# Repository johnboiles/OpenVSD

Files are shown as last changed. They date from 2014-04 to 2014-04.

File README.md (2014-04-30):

OpenVSD
=======
http://github.com/johnboiles/OpenVSD

A small board and accompanying Arduino firmware that allows you to turn a normal diaphragm pump into a variable speed diaphragm pump.

Bill of Materials
-----------------
1x 5V Pressure Sensor

1x IRFZ40 High-power MOSFET

1x MCP1416 MOSFET Driver

2x 0.1uF Capacitor

1x 1uF Capacitor

1x 5V Sparkfun Arduino Pro Micro 

TODO
____
Add flyback diode

Better footprint for screw terminals

Proper footprint for film capacitor

Silkscreen to indicate orientation of Arduino

Switch to default back to pressure switch

Debug LEDs

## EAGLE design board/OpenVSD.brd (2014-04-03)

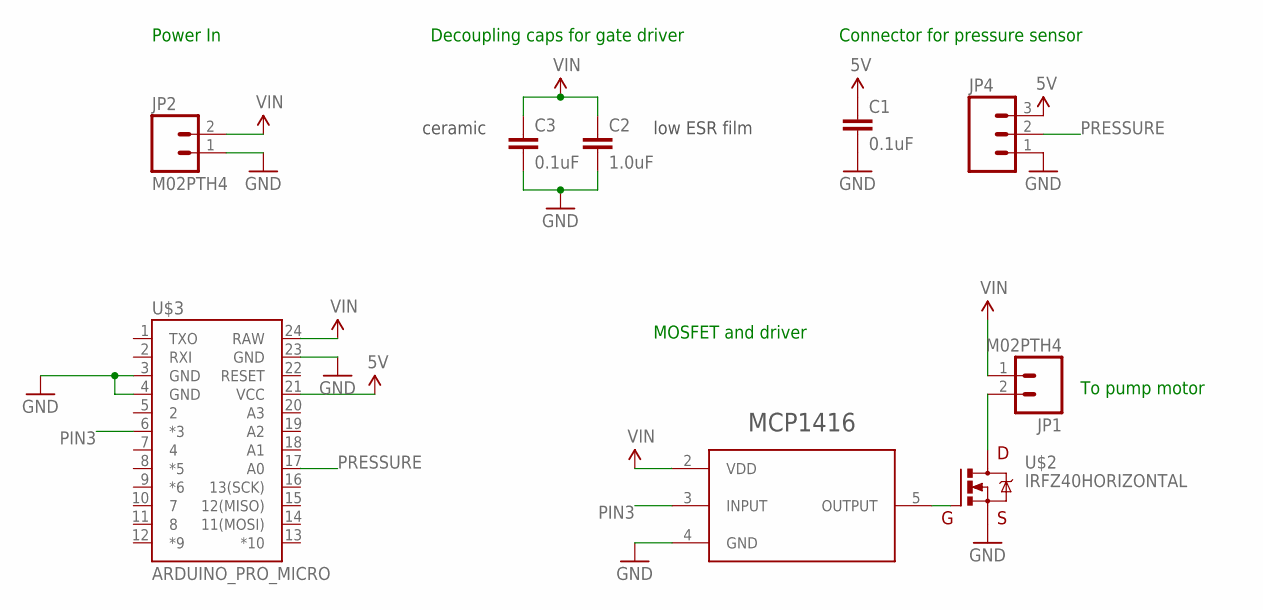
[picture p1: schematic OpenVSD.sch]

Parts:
C1, C3: 0.1uF; 0603-CAP
C2: 1.0uF; 0603-CAP
JP1, JP2: M02PTH4; 1X02_XTRA_BIG
JP4: M03PTH; 1X03
U$1: MCP1416; SOT23-5
U$2: IRFZ40HORIZONTAL; TO220
U$3: ARDUINO_PRO_MICRO

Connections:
5V: C1.1, JP4.3, U$3.21 (VCC)
GND: C1.2, C2.2, C3.2, JP2.1, JP4.1, U$1.4 (GND), U$2.3 (S), U$3.3 (GND), U$3.4 (GND), U$3.23 (GND)
unnamed: U$1.5 (OUTPUT), U$2.1 (G)
PIN3: U$1.3 (INPUT), U$3.6 (*3)
PRESSURE: JP4.2, U$3.17 (A0)
PUMP-: JP1.2, U$2.2 (D)
VIN: C2.1, C3.1, JP1.1, JP2.2, U$1.2 (VDD), U$3.24 (RAW)

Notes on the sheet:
low ESR film
ceramic
Power In
Decoupling caps for gate driver
Connector for pressure sensor
MOSFET and driver
To pump motor

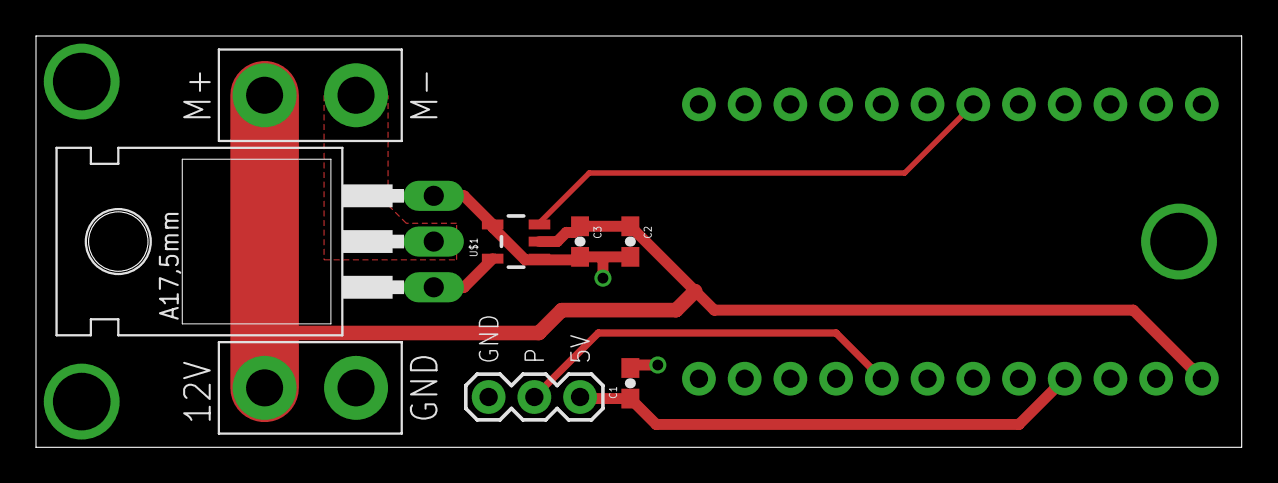
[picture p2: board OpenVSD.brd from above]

Board: 2 copper layers, 67.0 x 22.9 mm, 9 parts (0 on the bottom side), 7 nets.

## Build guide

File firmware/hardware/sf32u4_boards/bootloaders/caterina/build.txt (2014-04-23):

make clean
make PID=0x9209 F_CPU=16000000
copy Caterina.hex Caterina-wiflyin.hex
make clean
make PID=0x9207 F_CPU=8000000
copy Caterina.hex Caterina-lilypadusb.hex
make clean
make PID=0x9205 F_CPU=16000000
copy Caterina.hex Caterina-promicro16.hex
make clean
make PID=0x9203 F_CPU=8000000
copy Caterina.hex Caterina-promicro8.hex 
make clean
make PID=0x2B74 F_CPU=16000000
copy Caterina.hex Caterina-makey.hex
make clean
make PID=0xF100 F_CPU=8000000
copy Caterina.hex Caterina-fio.hex
make clean
make PID=0x920B F_CPU=16000000
copy Caterina.hex Caterina-minibench.hex

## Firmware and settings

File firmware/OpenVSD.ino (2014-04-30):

#include <PID_v1.h>

#define PRESSURE_SENSOR_PIN A0
#define DEBUG_LED_PIN 17
#define MOTOR_CONTROL_PIN 3
#define INITIAL_SETPOINT_PSI 40

#define VCC 5.0f
#define MOTOR_MINIMUM_PWM 100

// TODO: Call the PID method in an OCR interrupt
// TODO: Tune the pid
// https://controls.engin.umich.edu/wiki/index.php/PIDTuningClassical#Trial_and_Error
// http://www.ni.com/white-paper/3782/en/

void SerialReceive();
void SerialSend();
unsigned long serialTime; // This will help us know when to talk with processing

// Define Variables we'll be connecting to
double Setpoint, Input, Output;

// Specify the links and initial tuning parameters
PID myPID(&Input, &Output, &Setpoint, 8, 6, 0, DIRECT);

float readPressureSensor() {
    int analogValue = analogRead(PRESSURE_SENSOR_PIN);
    float voltage = (analogValue / 1024.0f) * VCC;
    // Pressure sensor returns between 0.5V – 4.5V, corresponding to 0-100psi
    float pressure = ((voltage - 0.5) / 4) * 100.0;
    return pressure;
}

ISR(TIMER1_COMPA_vect) {
    // (1 / 100s) * (16000000Hz / 256) = 625
    OCR1A = TCNT1 + 625;
    float pressure = readPressureSensor();
    Input = pressure;
    myPID.Compute();
    uint8_t motorOutput = Output;
    if (motorOutput <= MOTOR_MINIMUM_PWM || Input > 50.0) {
        motorOutput = 0;
    }
    analogWrite(MOTOR_CONTROL_PIN, motorOutput);
}

void setup() {
    // Disable interrupts
    cli();

    TCCR1A = 0;
    TCCR1B = 1 << CS12; // Clock / 256 (31250Hz or .000032)
    TCCR1C = 0; // not forcing output compare
    TCNT1 = 0; // set timer counter initial value (16 bit value)
    TIMSK1 = 1 << OCIE1A; // enable timer compare match 1A interrupt    

    Serial.begin(115200);
    pinMode(DEBUG_LED_PIN, OUTPUT);
    pinMode(PRESSURE_SENSOR_PIN, INPUT);
    pinMode(MOTOR_CONTROL_PIN, OUTPUT);
    digitalWrite(MOTOR_CONTROL_PIN, LOW);

    // Initialize the variables we're linked to
    Input = readPressureSensor();
    Setpoint = INITIAL_SETPOINT_PSI;

    // Turn the PID on
    myPID.SetOutputLimits(MOTOR_MINIMUM_PWM, 255);
    // For now, require manual initiation
    myPID.SetMode(AUTOMATIC);
    Output = 0;
    myPID.SetSampleTime(10);

    // Enable interrupts
    sei();
}

void loop() {
    // Send-receive with processing if it's time
    if (millis() > serialTime) {
        SerialReceive();
        SerialSend();
        serialTime += 350;
    }
}

/********************************************
 * Serial Communication functions / helpers
 ********************************************/


union {                // This Data structure lets
  byte asBytes[24];    // us take the byte array
  float asFloat[6];    // sent from processing and
}                      // easily convert it to a
foo;                   // float array



// getting float values from processing into the arduino
// was no small task.  the way this program does it is
// as follows:
//  * a float takes up 4 bytes.  in processing, convert
//    the array of floats we want to send, into an array
//    of bytes.
//  * send the bytes to the arduino
//  * use a data structure known as a union to convert
//    the array of bytes back into an array of floats

//  the bytes coming from the arduino follow the following
//  format:
//  0: 0=Manual, 1=Auto, else = ? error ?
//  1: 0=Direct, 1=Reverse, else = ? error ?
//  2-5: float setpoint
//  6-9: float input
//  10-13: float output
//  14-17: float P_Param
//  18-21: float I_Param
//  22-245: float D_Param
void SerialReceive()
{
  // read the bytes sent from Processing
  int index=0;
  byte Auto_Man = -1;
  byte Direct_Reverse = -1;
  while(Serial.available()&&index<26)
  {
    if(index==0) Auto_Man = Serial.read();
    else if(index==1) Direct_Reverse = Serial.read();
    else foo.asBytes[index-2] = Serial.read();
    index++;
  }

  // if the information we got was in the correct format,
  // read it into the system
  if(index==26  && (Auto_Man==0 || Auto_Man==1)&& (Direct_Reverse==0 || Direct_Reverse==1))
  {
    Setpoint=double(foo.asFloat[0]);
    //Input=double(foo.asFloat[1]);       // * the user has the ability to send the
                                          //   value of "Input"  in most cases (as
                                          //   in this one) this is not needed.
    if(Auto_Man==0)                       // * only change the output if we are in
    {                                     //   manual mode.  otherwise we'll get an
      Output=double(foo.asFloat[2]);      //   output blip, then the controller will
    }                                     //   overwrite.

    double p, i, d;                       // * read in and set the controller tunings
    p = double(foo.asFloat[3]);           //
    i = double(foo.asFloat[4]);           //
    d = double(foo.asFloat[5]);           //
    myPID.SetTunings(p, i, d);            //

    if(Auto_Man==0) myPID.SetMode(MANUAL);// * set the controller mode
    else myPID.SetMode(AUTOMATIC);             //

    if(Direct_Reverse==0) myPID.SetControllerDirection(DIRECT);// * set the controller Direction
    else myPID.SetControllerDirection(REVERSE);          //
  }
  Serial.flush();                         // * clear any random data from the serial buffer
}

// unlike our tiny microprocessor, the processing ap
// has no problem converting strings into floats, so
// we can just send strings.  much easier than getting
// floats from processing to here no?
void SerialSend() {
    Serial.print("PID ");
    Serial.print(Setpoint);
    Serial.print(" ");
    Serial.print(Input);
    Serial.print(" ");
    Serial.print(Output);
    Serial.print(" ");
    Serial.print(myPID.GetKp());
    Serial.print(" ");
    Serial.print(myPID.GetKi());
    Serial.print(" ");
    Serial.print(myPID.GetKd());
    Serial.print(" ");
    if(myPID.GetMode()==AUTOMATIC) Serial.print("Automatic");
    else Serial.print("Manual");
    Serial.print(" ");
    if(myPID.GetDirection()==DIRECT) Serial.println("Direct");
    else Serial.println("Reverse");
}

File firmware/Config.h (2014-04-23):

#define LEDPin 9
#define VibratePin 10
#define ButtonPin 6
#define DebugLEDPin 17

#define REQNPin A0
#define RDYNPin A1

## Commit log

2014-04-23 Using OCR interrupts for a more timely pid
2014-04-30 Working PID controller firmware

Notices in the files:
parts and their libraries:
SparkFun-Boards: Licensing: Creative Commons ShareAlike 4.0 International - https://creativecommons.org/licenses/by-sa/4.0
